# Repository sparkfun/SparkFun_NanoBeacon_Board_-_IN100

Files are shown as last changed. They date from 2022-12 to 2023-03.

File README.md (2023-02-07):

SparkFun NanoBeacon Board - IN100
====================================
<table class="table table-hover table-striped table-bordered">
  <tr align="center">
    <td></td>
    <td></td>
   </tr>
   <tr align="center">
    <td><a href="https://www.sparkfun.com/products/21327">SparkFun NanoBeacon Board - IN100</a></td>
    <td><a href="https://www.sparkfun.com/products/21293">SparkFun NanoBeacon Lite Board - IN100
   </tr>
</table>

The [SparkFun NanoBeacon Board - IN100](https://www.sparkfun.com/products/21327) and [SparkFun NanoBeacon Lite Board - IN100](https://www.sparkfun.com/products/21293) offer a 2.4 GHz wireless low energy BT beacon breakout with exceptional low power consumption features and minimal programming required. The board features the IN100 NanoBeacon<sup>&trade;</sup> from InPlay<sup>&trade;</sup>. The IN100 SoC is compliant with several standard 2.4 GHz protocols and has several built-in configurable features for device behavior that can drastically reduce power consumption allowing for continuous operation in the field for multiple years even with a connected device. The two versions all for users to prototype with the Lite (Development) version and then employ the standard (Production) version in large installation once your hardware and software design is complete. The board features the IN100 NanoBeacon<sup>&trade;</sup> from InPlay<sup>&trade;</sup>. The NanoBeacon config tool allows for software-free programming of the modules removing any need to perform any tricky programming for sending and receiving packets.

Repository Contents
-------------------

* **/Documents** - Datasheets, additional user documents
* **/Examples** - IN100 Config and Arduino example
* **/Hardware** - Eagle design files (.brd, .sch)
* **/Production** - Production panel files (.brd)

Documentation
--------------
* **[SparkFun NanoBeacon Board - IN100 Hookup Guide](https://learn.sparkfun.com/tutorials/sparkfun-nanobeacon-board---in100-hookup-guide)** - Basic Hookup Guide for the NanoBeacon boards.

Product Versions
-----------------

* [WRL-21327](https://www.sparkfun.com/products/21327) - NanoBeacon Board initial release (includes headers)
* [WRL-21293](https://www.sparkfun.com/products/21293) - NanoBeacon Lite Board initial release (includes Reset button and Power LED)

License Information
-------------------

This product is _**open source**_! 

Please review the LICENSE.md file for license information. 

If you have any questions or concerns on licensing, please contact technical support on our [SparkFun forums](https://forum.sparkfun.com/viewforum.php?f=152).

Distributed as-is; no warranty is given.

- Your friends at SparkFun.

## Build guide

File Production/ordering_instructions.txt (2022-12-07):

panel size, 169x117mm
PCB thickness, 1.6mm
number of layers, 2
soldermask color, Red
silkscreen color, White
oz copper, 1oz
finish, HASL lead free
stencils, top
pcs per panel, 24
min trace width, 0.2032mm / 0.0080in
min drill size, 0.3048mm / 0.0120in

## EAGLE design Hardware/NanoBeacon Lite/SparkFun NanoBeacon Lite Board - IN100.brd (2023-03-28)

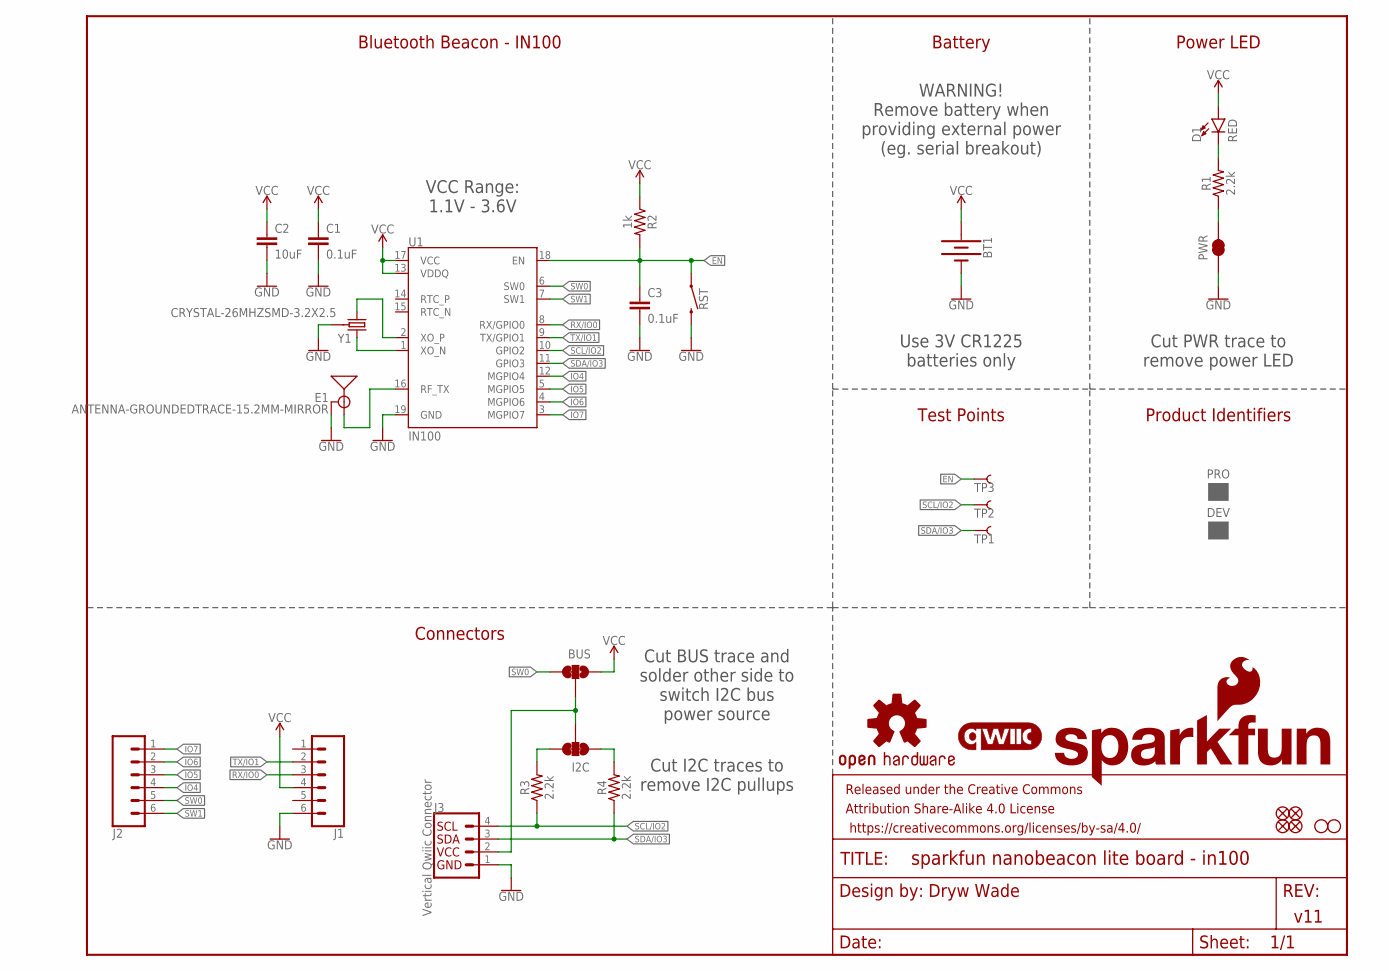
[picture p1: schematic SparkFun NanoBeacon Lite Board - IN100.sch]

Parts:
BT1: BATTERY-12MM_SMD_BOTH_PWR_PADS; BATTCON_12MM
BUS: JUMPER-SMT_3_1-NC_TRACE_SILK; SMT-JUMPER_3_1-NC_TRACE_SILK
C1, C3: 0.1uF; 0402-TIGHT
C2: 10uF; 0402-TIGHT
D1: RED; LED-0402
DEV: PROD_ID_PASTE_SILK; PRODUCT_IDENT_PASTE_SILK
E1: ANTENNA-GROUNDEDTRACE-15.2MM-MIRROR; TRACE_ANTENNA_2.4GHZ_15.2MM_MIRROR
FD1, FD2, FD3, FD4: FIDUCIAL1X2; FIDUCIAL-1X2
FRAME1: FRAME-LETTER; CREATIVE_COMMONS
H1, H2: STAND-OFF
I2C: JUMPER-SMT_3_2-NC_TRACE_SILK; SMT-JUMPER_3_2-NC_TRACE_SILK
J1, J2: CONN_06NO_SILK_NO_POP; 1X06_NO_SILK
J3: Vertical Qwiic Connector; JST04_1MM_VERT
LOGO1: OSHW-LOGOS; OSHW-LOGO-S
LOGO2: SFE_LOGO_NAME_FLAME.1_INCH; SFE_LOGO_NAME_FLAME_.1
LOGO3: QWIIC_LOGO_5MM; QWIIC_5MM
PRO: PROD_ID_PASTE_SILK; PRODUCT_IDENT_PASTE_SILK
PWR: JUMPER-SMT_2_NC_TRACE_SILK; SMT-JUMPER_2_NC_TRACE_SILK
R1, R3, R4: 2.2k; 0402-TIGHT
R2: 1k; 0402-TIGHT
RST: MOMENTARY-SWITCH-SPST-SMD-4.6X2.8MM; TACTILE_SWITCH_SMD_4.6X2.8MM
TP1, TP2, TP3: TEST-POINT3; PAD.03X.03
U1: IN100
Y1: CRYSTAL-26MHZSMD-3.2X2.5; CRYSTAL-SMD-3.2X2.5MM

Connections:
EN: C3.1, R2.2, RST.1, RST.2 (1), TP3.1, U1.18 (EN)
GND: BT1.GND (-), C1.2, C2.2, C3.2, E1.GND, J1.6, J3.1, PWR.1, RST.3 (2), RST.4 (2), U1.19 (GND), Y1.2 (GND), Y1.4 (GND)
IO4: J2.4, U1.12 (MGPIO4)
IO5: J2.3, U1.5 (MGPIO5)
IO6: J2.2, U1.4 (MGPIO6)
IO7: J2.1, U1.3 (MGPIO7)
unnamed: U1.1 (XO_N), Y1.3 (2)
unnamed: U1.2 (XO_P), Y1.1
unnamed: PWR.2, R1.1
unnamed: E1.ANT (SIGNAL), U1.16 (RF_TX)
unnamed: D1.C, R1.2
unnamed: I2C.1, R4.2
unnamed: BUS.2, I2C.2, J3.2
unnamed: I2C.3, R3.2
RX/IO0: J1.3, U1.8 (RX/GPIO0)
SCL/IO2: J3.4, R3.1, TP2.1, U1.10 (GPIO2)
SDA/IO3: J3.3, R4.1, TP1.1, U1.11 (GPIO3)
SW0: BUS.3, J2.5, U1.6 (SW0)
SW1: J2.6, U1.7 (SW1)
TX/IO1: J1.2, U1.9 (TX/GPIO1)
VCC: BT1.PWR@1 (+), BT1.PWR@2 (+), BUS.1, C1.1, C2.1, D1.A, J1.4, R2.1, U1.13 (VDDQ), U1.17 (VCC)

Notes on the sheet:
v11
Dryw Wade
Connectors
Battery
Bluetooth Beacon - IN100
Power LED
Cut PWR trace to remove power LED
VCC Range: 1.1V - 3.6V
Test Points
Cut I2C traces to remove I2C pullups
Cut BUS trace and solder other side to switch I2C bus power source
Use 3V CR1225 batteries only
WARNING\! Remove battery when providing external power (eg. serial breakout)
Product Identifiers

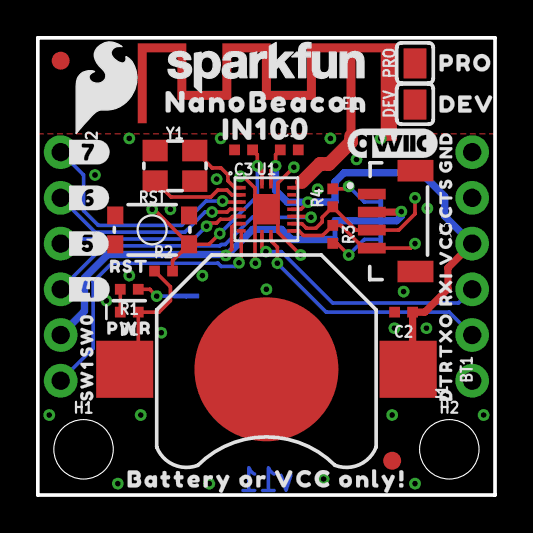
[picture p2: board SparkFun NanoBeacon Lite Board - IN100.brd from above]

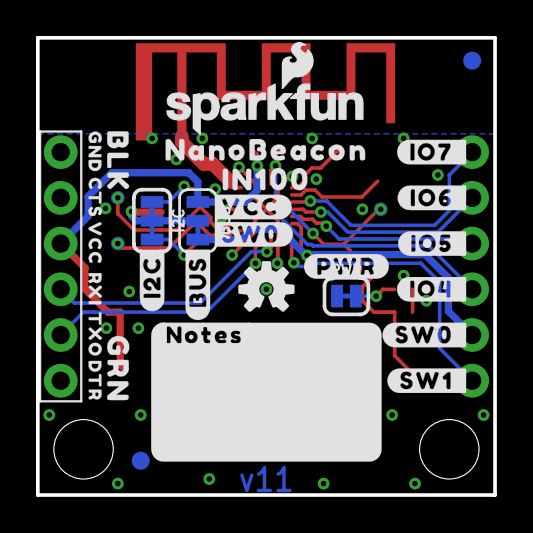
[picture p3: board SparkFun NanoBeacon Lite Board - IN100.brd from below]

Board: 2 copper layers, 25.4 x 25.4 mm, 63 parts (24 on the bottom side), 21 nets.

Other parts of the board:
U$1, U$29: NANOBEACON0
U$2: #_7#0
U$3: #_6#0
U$4: SFE_LOGO_NAME_.1
U$5, U$31: IN1000
U$6: #_5#0
U$7: #_4#0
U$8: SFE_LOGO_FLAME_.2
U$9: BATTERY_OR_VCC_ONLY##0
U$11: #I2C#0
U$12: #NOTES#0
U$13: #IO7_#0
U$14: #IO6_#0
U$15: #IO5_#0
U$16: #IO4_#0
U$17: #SW0_#0
U$18: #SW1_#0
U$19: #PWR#0
U$20: #SW0#3
U$21: SW00
U$22: SW10
U$23: RST0
U$24: #VCC#0
U$25: #BUS#0
U$26: PWR0
U$28: DEV0
U$30: PRO0

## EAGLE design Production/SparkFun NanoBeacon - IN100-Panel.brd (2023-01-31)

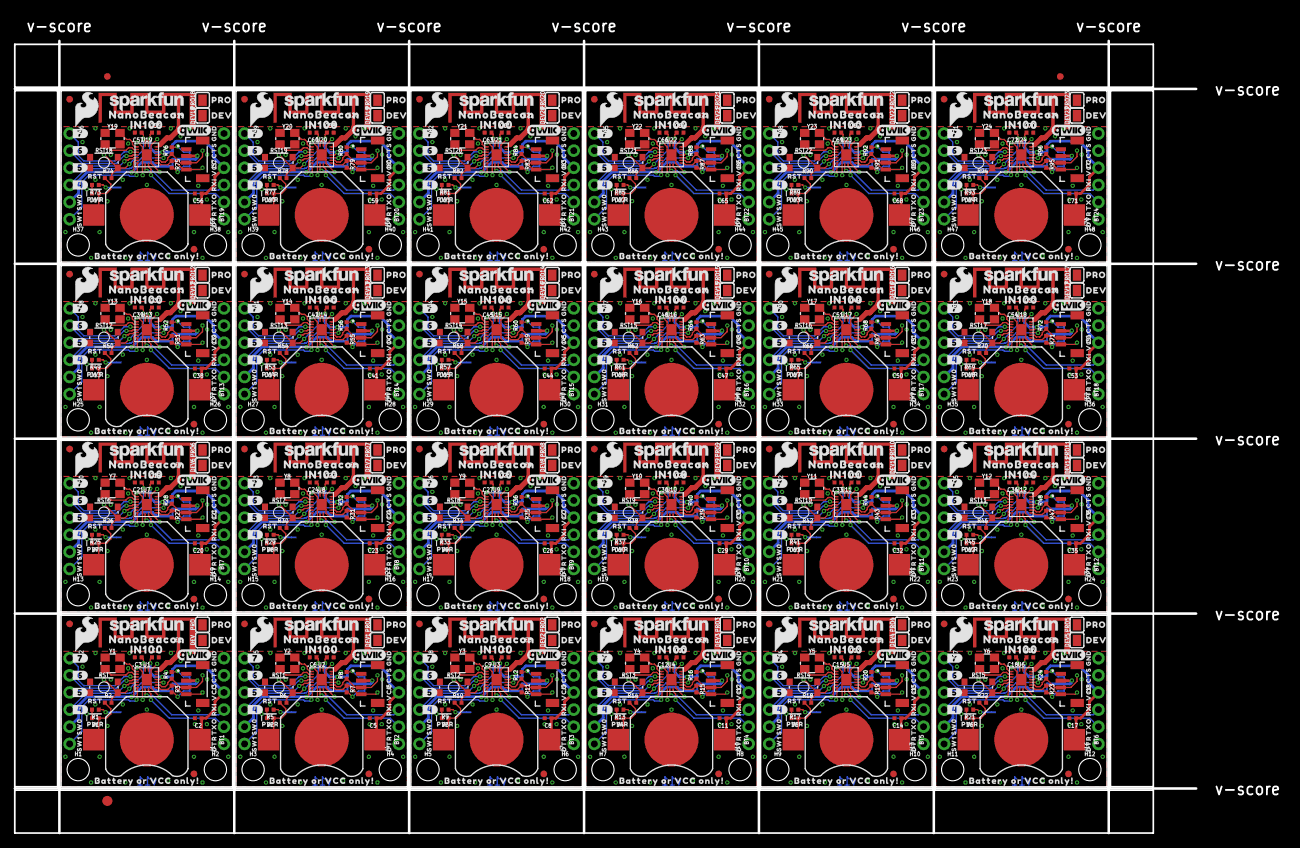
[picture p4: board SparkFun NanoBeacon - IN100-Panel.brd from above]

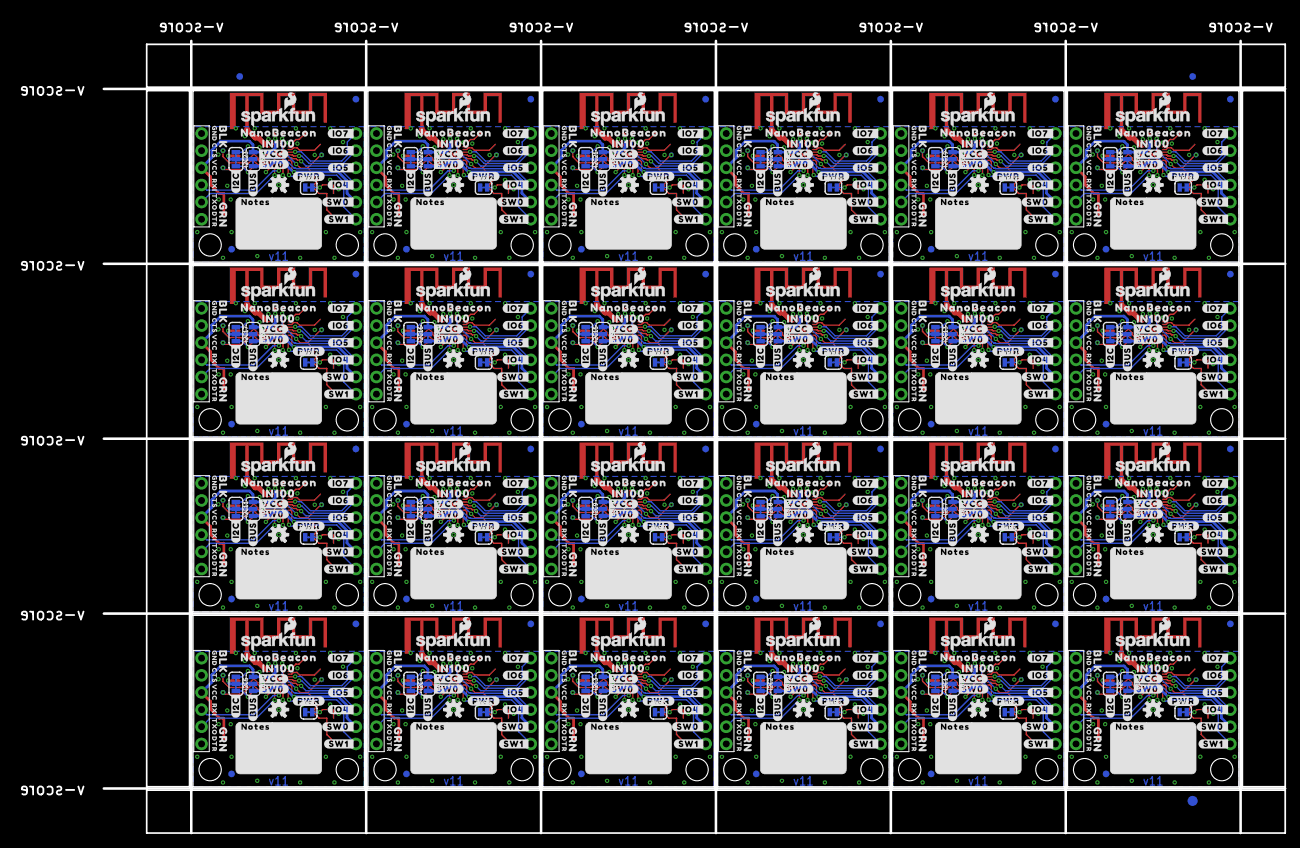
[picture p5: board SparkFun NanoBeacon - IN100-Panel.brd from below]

Board: 2 copper layers, 175.0 x 117.3 mm, 1494 parts (579 on the bottom side), 504 nets.

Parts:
BT1, BT2, BT3, BT4, BT5, BT6, BT7, BT8, BT9, BT10, BT11, BT12, BT13, BT14, BT15, BT16, BT17, BT18, BT19, BT20, BT21, BT22, BT23, BT24: BATTCON_12MM
BUS, BUS1, BUS2, BUS3, BUS4, BUS5, BUS6, BUS7, BUS8, BUS9, BUS10, BUS11, BUS12, BUS13, BUS14, BUS15, BUS16, BUS17, BUS18, BUS19, BUS20, BUS21, BUS22, BUS23: JUMPER-SMT_3_1-NC_TRACE_SILK; SMT-JUMPER_3_1-NC_TRACE_SILK
C1, C3, C4, C6, C7, C9, C10, C12, C13, C15, C16, C18, C19, C21, C22, C24, C25, C27, C28, C30, C31, C33, C34, C36, C37, C39, C40, C42, C43, C45, C46, C48, C49, C51, C52, C54, C55, C57, C58, C60, C61, C63, C64, C66, C67, C69, C70, C72: 0.1uF; 0402-TIGHT
C2, C5, C8, C11, C14, C17, C20, C23, C26, C29, C32, C35, C38, C41, C44, C47, C50, C53, C56, C59, C62, C65, C68, C71: 10uF; 0402-TIGHT
D1, D2, D3, D4, D5, D6, D7, D8, D9, D10, D11, D12, D13, D14, D15, D16, D17, D18, D19, D20, D21, D22, D23, D24: RED; LED-0402
DEV, DEV1, DEV2, DEV3, DEV4, DEV5, DEV6, DEV7, DEV8, DEV9, DEV10, DEV11, DEV12, DEV13, DEV14, DEV15, DEV16, DEV17, DEV18, DEV19, DEV20, DEV21, DEV22, DEV23: PROD_ID_PASTE_SILK; PRODUCT_IDENT_PASTE_SILK
E1, E2, E3, E4, E5, E6, E7, E8, E9, E10, E11, E12, E13, E14, E15, E16, E17, E18, E19, E20, E21, E22, E23, E24: ANTENNA-GROUNDEDTRACE-15.2MM; TRACE_ANTENNA_2.4GHZ_15.2MM
E$1, E$2, E$3, E$4: FIDUCIAL-1X2
E$5, E$6: FIDUCIAL-1.5X3
FD1, FD2, FD3, FD4, FD5, FD6, FD7, FD8, FD9, FD10, FD11, FD12, FD13, FD14, FD15, FD16, FD17, FD18, FD19, FD20, FD21, FD22, FD23, FD24, FD25, FD26, FD27, FD28, FD29, FD30, FD31, FD32, FD33, FD34, FD35, FD36, FD37, FD38, FD39, FD40, FD41, FD42, FD43, FD44, FD45, FD46, FD47, FD48, FD49, FD50, FD51, FD52, FD53, FD54, FD55, FD56, FD57, FD58, FD59, FD60, FD61, FD62, FD63, FD64, FD65, FD66, FD67, FD68, FD69, FD70, FD71, FD72, FD73, FD74, FD75, FD76, FD77, FD78, FD79, FD80, FD81, FD82, FD83, FD84, FD85, FD86, FD87, FD88, FD89, FD90, FD91, FD92, FD93, FD94, FD95, FD96: FIDUCIAL1X2; FIDUCIAL-1X2
H1, H2, H3, H4, H5, H6, H7, H8, H9, H10, H11, H12, H13, H14, H15, H16, H17, H18, H19, H20, H21, H22, H23, H24, H25, H26, H27, H28, H29, H30, H31, H32, H33, H34, H35, H36, H37, H38, H39, H40, H41, H42, H43, H44, H45, H46, H47, H48: STAND-OFF
I2C, I2C1, I2C2, I2C3, I2C4, I2C5, I2C6, I2C7, I2C8, I2C9, I2C10, I2C11, I2C12, I2C13, I2C14, I2C15, I2C16, I2C17, I2C18, I2C19, I2C20, I2C21, I2C22, I2C23: JUMPER-SMT_3_2-NC_TRACE_SILK; SMT-JUMPER_3_2-NC_TRACE_SILK
J1, J2, J4, J5, J7, J8, J10, J11, J13, J14, J16, J17, J19, J20, J22, J23, J25, J26, J28, J29, J31, J32, J34, J35, J37, J38, J40, J41, J43, J44, J46, J47, J49, J50, J52, J53, J55, J56, J58, J59, J61, J62, J64, J65, J67, J68, J70, J71: 1X06_NO_SILK
J3, J6, J9, J12, J15, J18, J21, J24, J27, J30, J33, J36, J39, J42, J45, J48, J51, J54, J57, J60, J63, J66, J69, J72: Vertical Qwiic Connector; JST04_1MM_VERT
LOGO1, LOGO4, LOGO7, LOGO10, LOGO13, LOGO16, LOGO19, LOGO22, LOGO25, LOGO28, LOGO31, LOGO34, LOGO37, LOGO40, LOGO43, LOGO46, LOGO49, LOGO52, LOGO55, LOGO58, LOGO61, LOGO64, LOGO67, LOGO70: OSHW-LOGOS; OSHW-LOGO-S
LOGO2, LOGO5, LOGO8, LOGO11, LOGO14, LOGO17, LOGO20, LOGO23, LOGO26, LOGO29, LOGO32, LOGO35, LOGO38, LOGO41, LOGO44, LOGO47, LOGO50, LOGO53, LOGO56, LOGO59, LOGO62, LOGO65, LOGO68, LOGO71: SFE_LOGO_NAME_FLAME.1_INCH; SFE_LOGO_NAME_FLAME_.1
LOGO3, LOGO6, LOGO9, LOGO12, LOGO15, LOGO18, LOGO21, LOGO24, LOGO27, LOGO30, LOGO33, LOGO36, LOGO39, LOGO42, LOGO45, LOGO48, LOGO51, LOGO54, LOGO57, LOGO60, LOGO63, LOGO66, LOGO69, LOGO72: QWIIC_LOGO_5MM; QWIIC_5MM
PRO, PRO1, PRO2, PRO3, PRO4, PRO5, PRO6, PRO7, PRO8, PRO9, PRO10, PRO11, PRO12, PRO13, PRO14, PRO15, PRO16, PRO17, PRO18, PRO19, PRO20, PRO21, PRO22, PRO23: PROD_ID_PASTE_SILK; PRODUCT_IDENT_PASTE_SILK
PWR, PWR1, PWR2, PWR3, PWR4, PWR5, PWR6, PWR7, PWR8, PWR9, PWR10, PWR11, PWR12, PWR13, PWR14, PWR15, PWR16, PWR17, PWR18, PWR19, PWR20, PWR21, PWR22, PWR23: JUMPER-SMT_2_NC_TRACE_SILK; SMT-JUMPER_2_NC_TRACE_SILK
R1, R3, R4, R5, R7, R8, R9, R11, R12, R13, R15, R16, R17, R19, R20, R21, R23, R24, R25, R27, R28, R29, R31, R32, R33, R35, R36, R37, R39, R40, R41, R43, R44, R45, R47, R48, R49, R51, R52, R53, R55, R56, R57, R59, R60, R61, R63, R64, R65, R67, R68, R69, R71, R72, R73, R75, R76, R77, R79, R80, R81, R83, R84, R85, R87, R88, R89, R91, R92, R93, R95, R96: 2.2k; 0402-TIGHT
R2, R6, R10, R14, R18, R22, R26, R30, R34, R38, R42, R46, R50, R54, R58, R62, R66, R70, R74, R78, R82, R86, R90, R94: 1k; 0402-TIGHT
RST, RST1, RST2, RST3, RST4, RST5, RST6, RST7, RST8, RST9, RST10, RST11, RST12, RST13, RST14, RST15, RST16, RST17, RST18, RST19, RST20, RST21, RST22, RST23: MOMENTARY-SWITCH-SPST-SMD-4.6X2.8MM; TACTILE_SWITCH_SMD_4.6X2.8MM
TP1, TP2, TP3, TP4, TP5, TP6, TP7, TP8, TP9, TP10, TP11, TP12, TP13, TP14, TP15, TP16, TP17, TP18, TP19, TP20, TP21, TP22, TP23, TP24, TP25, TP26, TP27, TP28, TP29, TP30, TP31, TP32, TP33, TP34, TP35, TP36, TP37, TP38, TP39, TP40, TP41, TP42, TP43, TP44, TP45, TP46, TP47, TP48, TP49, TP50, TP51, TP52, TP53, TP54, TP55, TP56, TP57, TP58, TP59, TP60, TP61, TP62, TP63, TP64, TP65, TP66, TP67, TP68, TP69, TP70, TP71, TP72: TEST-POINT3; PAD.03X.03
U1, U2, U3, U4, U5, U6, U7, U8, U9, U10, U11, U12, U13, U14, U15, U16, U17, U18, U19, U20, U21, U22, U23, U24: IN100
U$1, U$29, U$54, U$56, U$83, U$85, U$112, U$114, U$141, U$143, U$170, U$172, U$199, U$201, U$228, U$230, U$257, U$259, U$286, U$288, U$315, U$317, U$344, U$346, U$373, U$375, U$402, U$404, U$431, U$433, U$460, U$462, U$489, U$491, U$518, U$520, U$547, U$549, U$576, U$578, U$605, U$607, U$634, U$636, U$663, U$665, U$692, U$694: NANOBEACON0
U$2, U$27, U$60, U$89, U$118, U$147, U$176, U$205, U$234, U$263, U$292, U$321, U$350, U$379, U$408, U$437, U$466, U$495, U$524, U$553, U$582, U$611, U$640, U$669: #_7#0
U$3, U$32, U$61, U$90, U$119, U$148, U$177, U$206, U$235, U$264, U$293, U$322, U$351, U$380, U$409, U$438, U$467, U$496, U$525, U$554, U$583, U$612, U$641, U$670: #_6#0
U$4, U$10, U$59, U$88, U$117, U$146, U$175, U$204, U$233, U$262, U$291, U$320, U$349, U$378, U$407, U$436, U$465, U$494, U$523, U$552, U$581, U$610, U$639, U$668: SFE_LOGO_NAME_.1
U$5, U$31, U$55, U$57, U$84, U$86, U$113, U$115, U$142, U$144, U$171, U$173, U$200, U$202, U$229, U$231, U$258, U$260, U$287, U$289, U$316, U$318, U$345, U$347, U$374, U$376, U$403, U$405, U$432, U$434, U$461, U$463, U$490, U$492, U$519, U$521, U$548, U$550, U$577, U$579, U$606, U$608, U$635, U$637, U$664, U$666, U$693, U$695: IN1000
U$6, U$33, U$62, U$91, U$120, U$149, U$178, U$207, U$236, U$265, U$294, U$323, U$352, U$381, U$410, U$439, U$468, U$497, U$526, U$555, U$584, U$613, U$642, U$671: #_5#0
U$7, U$34, U$63, U$92, U$121, U$150, U$179, U$208, U$237, U$266, U$295, U$324, U$353, U$382, U$411, U$440, U$469, U$498, U$527, U$556, U$585, U$614, U$643, U$672: #_4#0
U$8, U$35, U$64, U$93, U$122, U$151, U$180, U$209, U$238, U$267, U$296, U$325, U$354, U$383, U$412, U$441, U$470, U$499, U$528, U$557, U$586, U$615, U$644, U$673: SFE_LOGO_FLAME_.2
U$9, U$58, U$87, U$116, U$145, U$174, U$203, U$232, U$261, U$290, U$319, U$348, U$377, U$406, U$435, U$464, U$493, U$522, U$551, U$580, U$609, U$638, U$667, U$696: BATTERY_OR_VCC_ONLY##0
U$11, U$45, U$74, U$103, U$132, U$161, U$190, U$219, U$248, U$277, U$306, U$335, U$364, U$393, U$422, U$451, U$480, U$509, U$538, U$567, U$596, U$625, U$654, U$683: #I2C#0
U$12, U$50, U$79, U$108, U$137, U$166, U$195, U$224, U$253, U$282, U$311, U$340, U$369, U$398, U$427, U$456, U$485, U$514, U$543, U$572, U$601, U$630, U$659, U$688: #NOTES#0
U$13, U$36, U$65, U$94, U$123, U$152, U$181, U$210, U$239, U$268, U$297, U$326, U$355, U$384, U$413, U$442, U$471, U$500, U$529, U$558, U$587, U$616, U$645, U$674: #IO7_#0
U$14, U$37, U$66, U$95, U$124, U$153, U$182, U$211, U$240, U$269, U$298, U$327, U$356, U$385, U$414, U$443, U$472, U$501, U$530, U$559, U$588, U$617, U$646, U$675: #IO6_#0
U$15, U$38, U$67, U$96, U$125, U$154, U$183, U$212, U$241, U$270, U$299, U$328, U$357, U$386, U$415, U$444, U$473, U$502, U$531, U$560, U$589, U$618, U$647, U$676: #IO5_#0
U$16, U$39, U$68, U$97, U$126, U$155, U$184, U$213, U$242, U$271, U$300, U$329, U$358, U$387, U$416, U$445, U$474, U$503, U$532, U$561, U$590, U$619, U$648, U$677: #IO4_#0
U$17, U$40, U$69, U$98, U$127, U$156, U$185, U$214, U$243, U$272, U$301, U$330, U$359, U$388, U$417, U$446, U$475, U$504, U$533, U$562, U$591, U$620, U$649, U$678: #SW0_#0
U$18, U$41, U$70, U$99, U$128, U$157, U$186, U$215, U$244, U$273, U$302, U$331, U$360, U$389, U$418, U$447, U$476, U$505, U$534, U$563, U$592, U$621, U$650, U$679: #SW1_#0
U$19, U$42, U$71, U$100, U$129, U$158, U$187, U$216, U$245, U$274, U$303, U$332, U$361, U$390, U$419, U$448, U$477, U$506, U$535, U$564, U$593, U$622, U$651, U$680: #PWR#0
U$20, U$46, U$75, U$104, U$133, U$162, U$191, U$220, U$249, U$278, U$307, U$336, U$365, U$394, U$423, U$452, U$481, U$510, U$539, U$568, U$597, U$626, U$655, U$684: #SW0#3
U$21, U$43, U$72, U$101, U$130, U$159, U$188, U$217, U$246, U$275, U$304, U$333, U$362, U$391, U$420, U$449, U$478, U$507, U$536, U$565, U$594, U$623, U$652, U$681: SW00
U$22, U$44, U$73, U$102, U$131, U$160, U$189, U$218, U$247, U$276, U$305, U$334, U$363, U$392, U$421, U$450, U$479, U$508, U$537, U$566, U$595, U$624, U$653, U$682: SW10
U$23, U$51, U$80, U$109, U$138, U$167, U$196, U$225, U$254, U$283, U$312, U$341, U$370, U$399, U$428, U$457, U$486, U$515, U$544, U$573, U$602, U$631, U$660, U$689: RST0
U$24, U$47, U$76, U$105, U$134, U$163, U$192, U$221, U$250, U$279, U$308, U$337, U$366, U$395, U$424, U$453, U$482, U$511, U$540, U$569, U$598, U$627, U$656, U$685: #VCC#0
U$25, U$48, U$77, U$106, U$135, U$164, U$193, U$222, U$251, U$280, U$309, U$338, U$367, U$396, U$425, U$454, U$483, U$512, U$541, U$570, U$599, U$628, U$657, U$686: #BUS#0
U$26, U$49, U$78, U$107, U$136, U$165, U$194, U$223, U$252, U$281, U$310, U$339, U$368, U$397, U$426, U$455, U$484, U$513, U$542, U$571, U$600, U$629, U$658, U$687: PWR0
U$28, U$52, U$81, U$110, U$139, U$168, U$197, U$226, U$255, U$284, U$313, U$342, U$371, U$400, U$429, U$458, U$487, U$516, U$545, U$574, U$603, U$632, U$661, U$690: DEV0
U$30, U$53, U$82, U$111, U$140, U$169, U$198, U$227, U$256, U$285, U$314, U$343, U$372, U$401, U$430, U$459, U$488, U$517, U$546, U$575, U$604, U$633, U$662, U$691: PRO0
Y1, Y2, Y3, Y4, Y5, Y6, Y7, Y8, Y9, Y10, Y11, Y12, Y13, Y14, Y15, Y16, Y17, Y18, Y19, Y20, Y21, Y22, Y23, Y24: CRYSTAL-26MHZSMD-3.2X2.5; CRYSTAL-SMD-3.2X2.5MM

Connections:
EN: C3.1, R2.2, RST.1, RST.2, TP3.1, U1.18
EN1: C6.1, R6.2, RST1.1, RST1.2, TP6.1, U2.18
EN2: C9.1, R10.2, RST2.1, RST2.2, TP9.1, U3.18
EN3: C12.1, R14.2, RST3.1, RST3.2, TP12.1, U4.18
EN4: C15.1, R18.2, RST4.1, RST4.2, TP15.1, U5.18
EN5: C18.1, R22.2, RST5.1, RST5.2, TP18.1, U6.18
EN6: C21.1, R26.2, RST6.1, RST6.2, TP21.1, U7.18
EN7: C24.1, R30.2, RST7.1, RST7.2, TP24.1, U8.18
EN8: C27.1, R34.2, RST8.1, RST8.2, TP27.1, U9.18
EN9: C30.1, R38.2, RST9.1, RST9.2, TP30.1, U10.18
EN10: C33.1, R42.2, RST10.1, RST10.2, TP33.1, U11.18
EN11: C36.1, R46.2, RST11.1, RST11.2, TP36.1, U12.18
EN12: C39.1, R50.2, RST12.1, RST12.2, TP39.1, U13.18
EN13: C42.1, R54.2, RST13.1, RST13.2, TP42.1, U14.18
EN14: C45.1, R58.2, RST14.1, RST14.2, TP45.1, U15.18
EN15: C48.1, R62.2, RST15.1, RST15.2, TP48.1, U16.18
EN16: C51.1, R66.2, RST16.1, RST16.2, TP51.1, U17.18
EN17: C54.1, R70.2, RST17.1, RST17.2, TP54.1, U18.18
EN18: C57.1, R74.2, RST18.1, RST18.2, TP57.1, U19.18
EN19: C60.1, R78.2, RST19.1, RST19.2, TP60.1, U20.18
EN20: C63.1, R82.2, RST20.1, RST20.2, TP63.1, U21.18
EN21: C66.1, R86.2, RST21.1, RST21.2, TP66.1, U22.18
EN22: C69.1, R90.2, RST22.1, RST22.2, TP69.1, U23.18
EN23: C72.1, R94.2, RST23.1, RST23.2, TP72.1, U24.18
GND: BT1.GND, C1.2, C2.2, C3.2, E1.GND, J1.6, J3.1, PWR.1, RST.3, RST.4, U1.19, Y1.2, Y1.4
GND1: BT2.GND, C4.2, C5.2, C6.2, E2.GND, J4.6, J6.1, PWR1.1, RST1.3, RST1.4, U2.19, Y2.2, Y2.4
GND2: BT3.GND, C7.2, C8.2, C9.2, E3.GND, J7.6, J9.1, PWR2.1, RST2.3, RST2.4, U3.19, Y3.2, Y3.4
GND3: BT4.GND, C10.2, C11.2, C12.2, E4.GND, J10.6, J12.1, PWR3.1, RST3.3, RST3.4, U4.19, Y4.2, Y4.4
GND4: BT5.GND, C13.2, C14.2, C15.2, E5.GND, J13.6, J15.1, PWR4.1, RST4.3, RST4.4, U5.19, Y5.2, Y5.4
GND5: BT6.GND, C16.2, C17.2, C18.2, E6.GND, J16.6, J18.1, PWR5.1, RST5.3, RST5.4, U6.19, Y6.2, Y6.4
GND6: BT7.GND, C19.2, C20.2, C21.2, E7.GND, J19.6, J21.1, PWR6.1, RST6.3, RST6.4, U7.19, Y7.2, Y7.4
GND7: BT8.GND, C22.2, C23.2, C24.2, E8.GND, J22.6, J24.1, PWR7.1, RST7.3, RST7.4, U8.19, Y8.2, Y8.4
GND8: BT9.GND, C25.2, C26.2, C27.2, E9.GND, J25.6, J27.1, PWR8.1, RST8.3, RST8.4, U9.19, Y9.2, Y9.4
GND9: BT10.GND, C28.2, C29.2, C30.2, E10.GND, J28.6, J30.1, PWR9.1, RST9.3, RST9.4, U10.19, Y10.2, Y10.4
GND10: BT11.GND, C31.2, C32.2, C33.2, E11.GND, J31.6, J33.1, PWR10.1, RST10.3, RST10.4, U11.19, Y11.2, Y11.4
GND11: BT12.GND, C34.2, C35.2, C36.2, E12.GND, J34.6, J36.1, PWR11.1, RST11.3, RST11.4, U12.19, Y12.2, Y12.4
GND12: BT13.GND, C37.2, C38.2, C39.2, E13.GND, J37.6, J39.1, PWR12.1, RST12.3, RST12.4, U13.19, Y13.2, Y13.4
GND13: BT14.GND, C40.2, C41.2, C42.2, E14.GND, J40.6, J42.1, PWR13.1, RST13.3, RST13.4, U14.19, Y14.2, Y14.4
GND14: BT15.GND, C43.2, C44.2, C45.2, E15.GND, J43.6, J45.1, PWR14.1, RST14.3, RST14.4, U15.19, Y15.2, Y15.4
GND15: BT16.GND, C46.2, C47.2, C48.2, E16.GND, J46.6, J48.1, PWR15.1, RST15.3, RST15.4, U16.19, Y16.2, Y16.4
GND16: BT17.GND, C49.2, C50.2, C51.2, E17.GND, J49.6, J51.1, PWR16.1, RST16.3, RST16.4, U17.19, Y17.2, Y17.4
GND17: BT18.GND, C52.2, C53.2, C54.2, E18.GND, J52.6, J54.1, PWR17.1, RST17.3, RST17.4, U18.19, Y18.2, Y18.4
GND18: BT19.GND, C55.2, C56.2, C57.2, E19.GND, J55.6, J57.1, PWR18.1, RST18.3, RST18.4, U19.19, Y19.2, Y19.4
GND19: BT20.GND, C58.2, C59.2, C60.2, E20.GND, J58.6, J60.1, PWR19.1, RST19.3, RST19.4, U20.19, Y20.2, Y20.4
GND20: BT21.GND, C61.2, C62.2, C63.2, E21.GND, J61.6, J63.1, PWR20.1, RST20.3, RST20.4, U21.19, Y21.2, Y21.4
GND21: BT22.GND, C64.2, C65.2, C66.2, E22.GND, J64.6, J66.1, PWR21.1, RST21.3, RST21.4, U22.19, Y22.2, Y22.4
GND22: BT23.GND, C67.2, C68.2, C69.2, E23.GND, J67.6, J69.1, PWR22.1, RST22.3, RST22.4, U23.19, Y23.2, Y23.4
GND23: BT24.GND, C70.2, C71.2, C72.2, E24.GND, J70.6, J72.1, PWR23.1, RST23.3, RST23.4, U24.19, Y24.2, Y24.4
IO1: J5.4, U2.12
IO2: J5.3, U2.5
IO3: J5.2, U2.4
IO4: J2.4, U1.12
IO5: J2.3, U1.5
IO6: J2.2, U1.4
IO7: J2.1, U1.3
IO8: J5.1, U2.3
IO9: J8.4, U3.12
IO10: J8.3, U3.5
IO11: J8.2, U3.4
IO12: J8.1, U3.3
IO13: J11.4, U4.12
IO14: J11.3, U4.5
IO15: J11.2, U4.4
IO16: J11.1, U4.3
IO17: J14.4, U5.12
IO18: J14.3, U5.5
IO19: J14.2, U5.4
IO20: J14.1, U5.3
IO21: J17.4, U6.12
IO22: J17.3, U6.5
IO23: J17.2, U6.4
IO24: J17.1, U6.3
IO25: J20.4, U7.12
IO26: J20.3, U7.5
IO27: J20.2, U7.4
IO28: J20.1, U7.3
IO29: J23.4, U8.12
IO30: J23.3, U8.5
IO31: J23.2, U8.4
IO32: J23.1, U8.3
IO33: J26.4, U9.12
IO34: J26.3, U9.5
IO35: J26.2, U9.4
IO36: J26.1, U9.3
IO37: J29.4, U10.12
IO38: J29.3, U10.5
IO39: J29.2, U10.4
IO40: J29.1, U10.3
IO41: J32.4, U11.12
IO42: J32.3, U11.5
IO43: J32.2, U11.4
IO44: J32.1, U11.3
IO45: J35.4, U12.12
IO46: J35.3, U12.5
IO47: J35.2, U12.4
IO48: J35.1, U12.3
IO49: J38.4, U13.12
IO50: J38.3, U13.5
IO51: J38.2, U13.4
IO52: J38.1, U13.3
IO53: J41.4, U14.12
IO54: J41.3, U14.5
IO55: J41.2, U14.4
IO56: J41.1, U14.3
IO57: J44.4, U15.12
IO58: J44.3, U15.5
IO59: J44.2, U15.4
IO60: J44.1, U15.3
IO61: J47.4, U16.12
IO62: J47.3, U16.5
IO63: J47.2, U16.4
IO64: J47.1, U16.3
IO65: J50.4, U17.12
IO66: J50.3, U17.5
IO67: J50.2, U17.4
IO68: J50.1, U17.3
IO69: J53.4, U18.12
IO70: J53.3, U18.5
IO71: J53.2, U18.4
IO72: J53.1, U18.3
IO73: J56.4, U19.12
IO74: J56.3, U19.5
IO75: J56.2, U19.4
IO76: J56.1, U19.3
IO77: J59.4, U20.12
IO78: J59.3, U20.5
IO79: J59.2, U20.4
IO80: J59.1, U20.3
IO81: J62.4, U21.12
IO82: J62.3, U21.5
IO83: J62.2, U21.4
IO84: J62.1, U21.3
IO85: J65.4, U22.12
IO86: J65.3, U22.5
IO87: J65.2, U22.4
IO88: J65.1, U22.3
IO89: J68.4, U23.12
IO90: J68.3, U23.5
IO91: J68.2, U23.4
IO92: J68.1, U23.3
IO93: J71.4, U24.12
IO94: J71.3, U24.5
IO95: J71.2, U24.4
IO96: J71.1, U24.3
unnamed: U1.1, Y1.3
unnamed: U1.2, Y1.1
unnamed: PWR.2, R1.1
unnamed: E1.ANT, U1.16
unnamed: D1.C, R1.2
unnamed: E2.ANT, U2.16
unnamed: I2C.1, R4.2
unnamed: BUS.2, I2C.2, J3.2
unnamed: I2C.3, R3.2
unnamed: U2.1, Y2.3
unnamed: U2.2, Y2.1
unnamed: I2C1.1, R8.2
unnamed: BUS1.2, I2C1.2, J6.2
unnamed: I2C1.3, R7.2
unnamed: PWR1.2, R5.1
unnamed: D2.C, R5.2
unnamed: E3.ANT, U3.16
unnamed: U3.1, Y3.3
unnamed: U3.2, Y3.1
unnamed: I2C2.1, R12.2
unnamed: BUS2.2, I2C2.2, J9.2
unnamed: I2C2.3, R11.2
unnamed: PWR2.2, R9.1
unnamed: D3.C, R9.2
unnamed: E4.ANT, U4.16
unnamed: U4.1, Y4.3
unnamed: U4.2, Y4.1
unnamed: I2C3.1, R16.2
unnamed: BUS3.2, I2C3.2, J12.2
unnamed: I2C3.3, R15.2
unnamed: PWR3.2, R13.1
unnamed: D4.C, R13.2
unnamed: E5.ANT, U5.16
unnamed: U5.1, Y5.3
unnamed: U5.2, Y5.1
unnamed: I2C4.1, R20.2
unnamed: BUS4.2, I2C4.2, J15.2
unnamed: I2C4.3, R19.2
unnamed: PWR4.2, R17.1
unnamed: D5.C, R17.2
unnamed: E6.ANT, U6.16
unnamed: U6.1, Y6.3
unnamed: U6.2, Y6.1
unnamed: I2C5.1, R24.2
unnamed: BUS5.2, I2C5.2, J18.2
unnamed: I2C5.3, R23.2
unnamed: PWR5.2, R21.1
unnamed: D6.C, R21.2
unnamed: E7.ANT, U7.16
unnamed: U7.1, Y7.3
unnamed: U7.2, Y7.1
unnamed: I2C6.1, R28.2
unnamed: BUS6.2, I2C6.2, J21.2
unnamed: I2C6.3, R27.2
unnamed: PWR6.2, R25.1
unnamed: D7.C, R25.2
unnamed: E8.ANT, U8.16
unnamed: U8.1, Y8.3
unnamed: U8.2, Y8.1
unnamed: I2C7.1, R32.2
unnamed: BUS7.2, I2C7.2, J24.2
unnamed: I2C7.3, R31.2
unnamed: PWR7.2, R29.1
unnamed: D8.C, R29.2
unnamed: E9.ANT, U9.16
unnamed: U9.1, Y9.3
unnamed: U9.2, Y9.1
unnamed: I2C8.1, R36.2
unnamed: BUS8.2, I2C8.2, J27.2
unnamed: I2C8.3, R35.2
unnamed: PWR8.2, R33.1
unnamed: D9.C, R33.2
unnamed: E10.ANT, U10.16
unnamed: U10.1, Y10.3
unnamed: U10.2, Y10.1
unnamed: I2C9.1, R40.2
unnamed: BUS9.2, I2C9.2, J30.2
unnamed: I2C9.3, R39.2
unnamed: PWR9.2, R37.1
unnamed: D10.C, R37.2
unnamed: E11.ANT, U11.16
unnamed: U11.1, Y11.3
unnamed: U11.2, Y11.1
unnamed: I2C10.1, R44.2
unnamed: BUS10.2, I2C10.2, J33.2
unnamed: I2C10.3, R43.2
unnamed: PWR10.2, R41.1
unnamed: D11.C, R41.2
unnamed: E12.ANT, U12.16
unnamed: U12.1, Y12.3
unnamed: U12.2, Y12.1
unnamed: I2C11.1, R48.2
unnamed: BUS11.2, I2C11.2, J36.2
unnamed: I2C11.3, R47.2
unnamed: PWR11.2, R45.1
unnamed: D12.C, R45.2
unnamed: E13.ANT, U13.16
unnamed: U13.1, Y13.3
unnamed: U13.2, Y13.1
unnamed: I2C12.1, R52.2
unnamed: BUS12.2, I2C12.2, J39.2
unnamed: I2C12.3, R51.2
unnamed: PWR12.2, R49.1
unnamed: D13.C, R49.2
unnamed: E14.ANT, U14.16
unnamed: U14.1, Y14.3
unnamed: U14.2, Y14.1
unnamed: I2C13.1, R56.2
unnamed: BUS13.2, I2C13.2, J42.2
unnamed: I2C13.3, R55.2
unnamed: PWR13.2, R53.1
unnamed: D14.C, R53.2
unnamed: E15.ANT, U15.16
unnamed: U15.1, Y15.3
unnamed: U15.2, Y15.1
unnamed: I2C14.1, R60.2
unnamed: BUS14.2, I2C14.2, J45.2
unnamed: I2C14.3, R59.2
unnamed: PWR14.2, R57.1
unnamed: D15.C, R57.2
unnamed: E16.ANT, U16.16
unnamed: U16.1, Y16.3
unnamed: U16.2, Y16.1
unnamed: I2C15.1, R64.2
unnamed: BUS15.2, I2C15.2, J48.2
unnamed: I2C15.3, R63.2
unnamed: PWR15.2, R61.1
unnamed: D16.C, R61.2
unnamed: E17.ANT, U17.16
unnamed: U17.1, Y17.3
unnamed: U17.2, Y17.1
unnamed: I2C16.1, R68.2
unnamed: BUS16.2, I2C16.2, J51.2
unnamed: I2C16.3, R67.2
unnamed: PWR16.2, R65.1
unnamed: D17.C, R65.2
unnamed: E18.ANT, U18.16
unnamed: U18.1, Y18.3
unnamed: U18.2, Y18.1
unnamed: I2C17.1, R72.2
unnamed: BUS17.2, I2C17.2, J54.2
unnamed: I2C17.3, R71.2
unnamed: PWR17.2, R69.1
unnamed: D18.C, R69.2
unnamed: E19.ANT, U19.16
unnamed: U19.1, Y19.3
unnamed: U19.2, Y19.1
unnamed: I2C18.1, R76.2
unnamed: BUS18.2, I2C18.2, J57.2
unnamed: I2C18.3, R75.2
unnamed: PWR18.2, R73.1
unnamed: D19.C, R73.2
unnamed: E20.ANT, U20.16
unnamed: U20.1, Y20.3
unnamed: U20.2, Y20.1
unnamed: I2C19.1, R80.2
unnamed: BUS19.2, I2C19.2, J60.2
unnamed: I2C19.3, R79.2
unnamed: PWR19.2, R77.1
unnamed: D20.C, R77.2
unnamed: E21.ANT, U21.16
unnamed: U21.1, Y21.3
unnamed: U21.2, Y21.1
unnamed: I2C20.1, R84.2
unnamed: BUS20.2, I2C20.2, J63.2
unnamed: I2C20.3, R83.2
unnamed: PWR20.2, R81.1
unnamed: D21.C, R81.2
unnamed: E22.ANT, U22.16
unnamed: U22.1, Y22.3
unnamed: U22.2, Y22.1
unnamed: I2C21.1, R88.2
unnamed: BUS21.2, I2C21.2, J66.2
unnamed: I2C21.3, R87.2
unnamed: PWR21.2, R85.1
unnamed: D22.C, R85.2
unnamed: E23.ANT, U23.16
unnamed: U23.1, Y23.3
unnamed: U23.2, Y23.1
unnamed: I2C22.1, R92.2
unnamed: BUS22.2, I2C22.2, J69.2
unnamed: I2C22.3, R91.2
unnamed: PWR22.2, R89.1
unnamed: D23.C, R89.2
unnamed: E24.ANT, U24.16
unnamed: U24.1, Y24.3
unnamed: U24.2, Y24.1
unnamed: I2C23.1, R96.2
unnamed: BUS23.2, I2C23.2, J72.2
unnamed: I2C23.3, R95.2
unnamed: PWR23.2, R93.1
unnamed: D24.C, R93.2
RX/IO0: J1.3, U1.8
RX/IO1: J4.3, U2.8
RX/IO2: J7.3, U3.8
RX/IO3: J10.3, U4.8
RX/IO4: J13.3, U5.8
RX/IO5: J16.3, U6.8
RX/IO6: J19.3, U7.8
RX/IO7: J22.3, U8.8
RX/IO8: J25.3, U9.8
RX/IO9: J28.3, U10.8
RX/IO10: J31.3, U11.8
RX/IO11: J34.3, U12.8
RX/IO12: J37.3, U13.8
RX/IO13: J40.3, U14.8
RX/IO14: J43.3, U15.8
RX/IO15: J46.3, U16.8
RX/IO16: J49.3, U17.8
RX/IO17: J52.3, U18.8
RX/IO18: J55.3, U19.8
RX/IO19: J58.3, U20.8
RX/IO20: J61.3, U21.8
RX/IO21: J64.3, U22.8
RX/IO22: J67.3, U23.8
RX/IO23: J70.3, U24.8
SCL/IO1: J6.4, R7.1, TP5.1, U2.10
SCL/IO2: J3.4, R3.1, TP2.1, U1.10
SCL/IO3: J9.4, R11.1, TP8.1, U3.10
SCL/IO4: J12.4, R15.1, TP11.1, U4.10
SCL/IO5: J15.4, R19.1, TP14.1, U5.10
SCL/IO6: J18.4, R23.1, TP17.1, U6.10
SCL/IO7: J21.4, R27.1, TP20.1, U7.10
SCL/IO8: J24.4, R31.1, TP23.1, U8.10
SCL/IO9: J27.4, R35.1, TP26.1, U9.10
SCL/IO10: J30.4, R39.1, TP29.1, U10.10
SCL/IO11: J33.4, R43.1, TP32.1, U11.10
SCL/IO12: J36.4, R47.1, TP35.1, U12.10
SCL/IO13: J39.4, R51.1, TP38.1, U13.10
SCL/IO14: J42.4, R55.1, TP41.1, U14.10
SCL/IO15: J45.4, R59.1, TP44.1, U15.10
SCL/IO16: J48.4, R63.1, TP47.1, U16.10
SCL/IO17: J51.4, R67.1, TP50.1, U17.10
SCL/IO18: J54.4, R71.1, TP53.1, U18.10
SCL/IO19: J57.4, R75.1, TP56.1, U19.10
SCL/IO20: J60.4, R79.1, TP59.1, U20.10
SCL/IO21: J63.4, R83.1, TP62.1, U21.10
SCL/IO22: J66.4, R87.1, TP65.1, U22.10
SCL/IO23: J69.4, R91.1, TP68.1, U23.10
SCL/IO24: J72.4, R95.1, TP71.1, U24.10
SDA/IO1: J6.3, R8.1, TP4.1, U2.11
SDA/IO2: J9.3, R12.1, TP7.1, U3.11
SDA/IO3: J3.3, R4.1, TP1.1, U1.11
SDA/IO4: J12.3, R16.1, TP10.1, U4.11
SDA/IO5: J15.3, R20.1, TP13.1, U5.11
SDA/IO6: J18.3, R24.1, TP16.1, U6.11
SDA/IO7: J21.3, R28.1, TP19.1, U7.11
SDA/IO8: J24.3, R32.1, TP22.1, U8.11
SDA/IO9: J27.3, R36.1, TP25.1, U9.11
SDA/IO10: J30.3, R40.1, TP28.1, U10.11
SDA/IO11: J33.3, R44.1, TP31.1, U11.11
SDA/IO12: J36.3, R48.1, TP34.1, U12.11
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

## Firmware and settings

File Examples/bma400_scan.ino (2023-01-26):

#include <BLEDevice.h>
#include <BLEUtils.h>
#include <BLEScan.h>
#include <BLEAdvertisedDevice.h>
#include <BLEEddystoneURL.h>
#include <BLEEddystoneTLM.h>
#include <BLEBeacon.h>

int scanTime = 1;
BLEScan *pBLEScan;

// This class is used for the onResult() callback function
class MyAdvertisedDeviceCallbacks : public BLEAdvertisedDeviceCallbacks
{
  // This function is called each time a new BLE device is found during a scan
  void onResult(BLEAdvertisedDevice advertisedDevice)
  {
    // Some BLE devices don't have names, so we'll ignore the ones that don't
    if (advertisedDevice.haveName())
    {
      // Check if the name of this device matches our beacon
      const char* deviceName = advertisedDevice.getName().c_str();
      if(strncmp(deviceName, "BMA400_Data", strlen(deviceName)) == 0)
      {
        // This is our beacon! Print out the received signal strength
        Serial.printf("RSSI: %i\n", advertisedDevice.getRSSI());

        // Copy the manufacturer data into a buffer
        uint8_t manufacturerData[32];
        std::string manufacturerDataString = advertisedDevice.getManufacturerData();
        manufacturerDataString.copy((char*) manufacturerData, manufacturerDataString.length(), 0);

        // The first 2 bytes are the manufaturer ID, print those out
        uint16_t manufacturerID = (manufacturerData[0] << 8 ) | manufacturerData[1];
        Serial.printf("Manufacturer ID: %04X\n", manufacturerID);

        // The next byte is the battery voltage, units are 31.25mV/LSB
        uint16_t voltageRaw = manufacturerData[2];
        float voltage = voltageRaw * 0.03125;
        Serial.printf("Voltage: %.2f\n", voltage);
        
        // Last 6 bytes are the raw acceleration data for the x/y/z axes, as specified in the BMA400 datasheet
        int16_t xRaw = ((uint16_t) manufacturerData[4] << 8) | manufacturerData[3];
        int16_t yRaw = ((uint16_t) manufacturerData[6] << 8) | manufacturerData[5];
        int16_t zRaw = ((uint16_t) manufacturerData[8] << 8) | manufacturerData[7];

        // The raw values are 12-bit signed values, so we need to make sure negative values are correctly signed
        if(xRaw > 2047) xRaw -= 4096;
        if(yRaw > 2047) yRaw -= 4096;
        if(zRaw > 2047) zRaw -= 4096;

        // Convert the raw values to acceleration in g's
        // BMA400 defaults to +/- 4g over the whole 12-bit range
        float xAcc = xRaw * 4.0 / pow(2, 11);
        float yAcc = yRaw * 4.0 / pow(2, 11);
        float zAcc = zRaw * 4.0 / pow(2, 11);

        // Now print out the x/y/z acceleration values
        Serial.printf("X: %.2f Y: %.2f Z: %.2f\n\n", xAcc, yAcc, zAcc);

        // Now that we've found our beacon and logged everything, we can stop the scan
        pBLEScan->stop();
      }
    }
  }
};

void setup()
{
  // Set up serial
  Serial.begin(115200);
  Serial.println("BLE scan sketch begin!");

  // Create new BLE scan object
  BLEDevice::init("");
  pBLEScan = BLEDevice::getScan();

  // Set callback for when new devices are found in the scan
  pBLEScan->setAdvertisedDeviceCallbacks(new MyAdvertisedDeviceCallbacks());

  // Enable active scanning. It uses more power, but is faster
  pBLEScan->setActiveScan(true);

  // Set the scan interval and window in milliseconds
  pBLEScan->setInterval(100);
  pBLEScan->setWindow(99);
}

void loop()
{
  // Start new scan. This blocks until finished
  BLEScanResults foundDevices = pBLEScan->start(scanTime, false);

  // Scan finished, delete results to release memory
  pBLEScan->clearResults();
}

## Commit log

2022-11-14 Add initial schematic and board layout
    [SparkFun_Bluetooth_Beacon_IN100.brd, SparkFun_Bluetooth_Beacon_IN100.sch]
2022-11-14 Pre-review cleanup
    Clean up schematic
    Add "programmed" checkbox to bottom silk
    Add SW0 and SW1 to top silk
    Update measures
    [SparkFun_Bluetooth_Beacon_IN100.brd, SparkFun_Bluetooth_Beacon_IN100.sch]
2022-11-15 Design review updates
    Add TX/RX labels to IN100 symbol
    Add text to jumpers in schematic
    Add VCC range to schematic
    Rename PWR jumper in schematic
    Increase crystal trace width to 10mil
    Add more GND vias near RF trace
    [SparkFun_Bluetooth_Beacon_IN100.brd, SparkFun_Bluetooth_Beacon_IN100.sch]
2022-11-15 Design review updates
    Update serial connector silk on back side
    Change "Programmed" checkbox to "Board info" silk region for general notes
    [SparkFun_Bluetooth_Beacon_IN100.brd]
2022-11-15 Add v01 panel
    [SparkFun_Bluetooth_Beacon_IN100-Panel.GBL, SparkFun_Bluetooth_Beacon_IN100-Panel.GBO, SparkFun_Bluetooth_Beacon_IN100-Panel.GBP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]
2022-11-17 Add suggestions from InPlay
    Add diodes to isolate VIN from V_BATT
    Add RC filter to EN
    Add jumper for I2C power selection
    Add bulk capacitor to SW0 output
    Reroute entire board to accommodate changes
    [SparkFun_Bluetooth_Beacon_IN100.brd, SparkFun_Bluetooth_Beacon_IN100.sch]
2022-11-30 V10 updates
    Bump version number to v10
    Extend pads of IN100 to get better fillet outside of chip
    Change all 0603 components to 0402
    Add I2C pullups
    Swap jumper for I2C bus power to make SW0 default
    Add I2C test points
    Reposition and reroute for above changes
    Add silk label to power LED
    Remove "Serial" silk from bottom
    [SparkFun_Bluetooth_Beacon_IN100.brd, SparkFun_Bluetooth_Beacon_IN100.sch]
2022-12-02 Design review updates
    Remove power management diodes
    Space out I2C test points
    Increase VCC and SW0 net widths to 16 mil
    Move crystal to avoid interference from VCC trace underneath
    Change "Board info" silk to "Notes"
    Add measures for coin cell
    Add note in schematic to use CR1225 battery
    Add warning in schematic and silk to remove battery when powering with VCC
    [SparkFun_Bluetooth_Beacon_IN100.brd, SparkFun_Bluetooth_Beacon_IN100.sch]
2022-12-06 v10 updates
    Add reset button
    Remove SW0 capacitor
    Remove top mounting holes
    Add solder pads to identify development / production SKUs
    Add Qwiic logo
    Increase SFE flame silk logo
    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
    [SparkFun_Bluetooth_Beacon_IN100.brd, SparkFun_Bluetooth_Beacon_IN100.sch]
2022-12-06 Design review updates
    Improve GND continuity
    Add some small restrict regions to improve copper pour
    Nudge "PROD" and "DEV" text away from pads
    In schematic, move reset button to near main IC, and replace with Product Identifier pads
    [SparkFun_Bluetooth_Beacon_IN100.brd, SparkFun_Bluetooth_Beacon_IN100.sch]
2022-12-07 Change identifier pads to solid versions
    Also approve extraneous DRC jumper overlap error
    [SparkFun_Bluetooth_Beacon_IN100.brd, SparkFun_Bluetooth_Beacon_IN100.sch]
2022-12-07 Checklist updates
    Add PROD_ID to IN100 device
    Add name and value to IN100 footprint
    Add selective solder paths to layer 48
    Move product identifier pads out of selective solder path
    [SparkFun_Bluetooth_Beacon_IN100.brd, SparkFun_Bluetooth_Beacon_IN100.sch]
2022-12-07 Add EN test point
    [SparkFun_Bluetooth_Beacon_IN100.brd, SparkFun_Bluetooth_Beacon_IN100.sch]
2022-12-07 Add v10 production files
    Remove v01 production files
    [SparkFun_Bluetooth_Beacon_IN100-Panel.GBL, SparkFun_Bluetooth_Beacon_IN100-Panel.GBO, SparkFun_Bluetooth_Beacon_IN100-Panel.GBP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]
2023-01-11 Create separate panel for production SKU PnP
    [SparkFun_Bluetooth_Beacon_IN100-Panel.brd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]
2023-01-11 Revert "Create separate panel for production SKU PnP"
    This reverts commit 7dec68e7d5254ea66e83b2d8774bd0da3de712ae.
    [SparkFun_Bluetooth_Beacon_IN100-Panel.brd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]
2023-01-11 Create separate board file for production SKU PnP
    [SparkFun_Bluetooth_Beacon_IN100.brd, SparkFun_Bluetooth_Beacon_IN100.sch]
2023-01-26 Fix production SKU board and schematic being inconsistent
    [SparkFun_Bluetooth_Beacon_IN100.brd, SparkFun_Bluetooth_Beacon_IN100.sch]
2023-01-26 Product Name Update & Examples
    Renaming board files to match product names. Adding Examples folder for BMA400 demo including Config and Arduino files.
    [SparkFun NanoBeacon Development Board - IN100.brd, SparkFun NanoBeacon Development Board - IN100.sch, SparkFun NanoBeacon Production Board - IN100.brd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]
2023-01-30 v11 updates
    Bump version number
    Update board name in silk
    Change "VBATT" silk to "Battery"
    [SparkFun NanoBeacon Development Board - IN100.brd, SparkFun NanoBeacon Development Board - IN100.sch, SparkFun NanoBeacon Production Board - IN100.brd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]
2023-01-30 Minor updates
    Nudge bottom SFE silk logo away from edge
    Increase size of Qwiic logo
    Nudge vias along bottom edge
    [SparkFun NanoBeacon Development Board - IN100.brd, SparkFun NanoBeacon Development Board - IN100.sch, SparkFun NanoBeacon Production Board - IN100.brd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]
2023-01-31 Update panel files for v11
    [SparkFun NanoBeacon - IN100-Panel.brd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]
2023-02-08 Update filenames
    Updating file names to match final product names.
    [SparkFun NanoBeacon Board - IN100.brd, SparkFun NanoBeacon Board - IN100.sch, SparkFun NanoBeacon Lite Board - IN100.brd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]
2023-03-28 Remove library file
    Part is in SFE Eagle library, update part in design
    [SparkFun NanoBeacon Board - IN100.brd, SparkFun NanoBeacon Board - IN100.sch, SparkFun NanoBeacon Lite Board - IN100.brd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]

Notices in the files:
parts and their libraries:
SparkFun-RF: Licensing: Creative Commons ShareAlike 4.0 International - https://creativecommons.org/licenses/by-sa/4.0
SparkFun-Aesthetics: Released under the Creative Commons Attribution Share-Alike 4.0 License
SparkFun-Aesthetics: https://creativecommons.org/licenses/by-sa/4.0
